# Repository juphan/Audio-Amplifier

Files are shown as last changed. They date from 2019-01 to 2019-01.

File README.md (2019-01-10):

# Audio-Amplifier
This audio amplifier circuit was designed to allow the user to physically change the volume of a plugged-in phone (or music player) by turning the dial of a connected dual gauge potentiometer. A phone needs to be connected in series with the potentiometer and the circuit. 

Phone -> Potentiometer -> Circuit (X7)

The circuit will also be connected to a wall outlet and be powered by dampening the incoming AC voltage into DC voltage. A pair of headphones can be connected to the board to project the amplified audio. 

The circuit design was taken from a schematic. This schematic was re-created on Eagle and board layout was performed on a 3x3 inch board. This project mainly involved setting up a circuit, basic board layout, ordering components, and soldering through hole components.

*Note - There is a small design issue. A female pin connector was not included on the circuit for the ground pin of the potentiometer. However, this issue can be solved by manually connecting the ground pin of the potentiometer with another ground in the circuit.

This repository contains the schematic that I re-created in Eagle, the board layout, the generated Gerber files from board layout, and the components list. There is also a picture of the final product.

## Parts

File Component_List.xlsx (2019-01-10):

*Note - Quantity of parts are meant for 3 sets of the Audio Amplifier circuit
Index | Piece | Quantity | Description | Part Number | Description | Unit Price ($) | Extended Price ($)
1 | Capacitors | 30 | 10uF | 445-8290-ND | CAP CER 10UF 16V X5R RADIAL | 0.319 | 9.57
2 |  | 6 | 1000uF | 1189-1583-1-ND | CAP ALUM 1000UF 20% 25V RADIAL | 0.67 | 4.02
3 |  | 12 | 0.1uF | 505-MKS2.1/63/5 (https://www.mouser.com/ProductDetail/WIMA/MKS2-1-63-5/?qs=sGAEpiMZZMv1cc3ydrPrFwgzP98AO9idLqHoQndgxWA%3d) | Film Capacitors 63V .1uF 5% | 0.289 | 3.47
4 |  | 6 | 680pF | 505-FKP2680/100/5, wima (https://www.mouser.com/ProductDetail/WIMA/FKP2D006801D00JSSD/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) | Film Capacitors 100V 680pF 5% TOL PCM 5 | 0.76 | 4.56
5 | Resistors | 10 | 100 ohm | S100QCT-ND | RES 100 OHM 1/4W 5% CF MINI | 0.041 | 0.41
6 |  | 10 | 1.1 kohm | S1.1KQCT-ND | RES 1.1K OHM 1/4W 5% CF MINI | 0.041 | 0.41
7 |  | 25 | 1 kohm | S1KQCT-ND | RES 1K OHM 1/4W 5% CF MINI | 0.03 | 0.75
8 |  | 10 | 3.3 kohm | S3.3KQCT-ND | RES 3.3K OHM 1/4W 5% CF MINI | 0.041 | 0.41
9 |  | 12 | 56 ohm | BC3946CT-ND | RES 56 OHM 0.4W 5% AXIAL | 0.197 | 2.36
10 |  | 6 | 56 ohm/ 1W | P56W-1BK-ND | RES 56 OHM 1W 5% AXIAL | 0.24 | 1.44
11 |  | 12 | 10 ohm | BC3924CT-ND | RES 10 OHM 0.4W 1% AXIAL | 0.197 | 2.36
12 | Diodes | 100 | 1N4148 DIODE | 1N4148FS-ND | DIODE GEN PURP 100V 200MA DO35 | 0.0345 | 3.45
13 |  | 12 | 1N4004 DIODE | 1N4004-TPMSCT-ND | DIODE GEN PURP 400V 1A DO41 | 0.104 | 1.25
14 | Voltage Regs | 3 | V_REG POS | LM338T/NOPB-ND | IC REG LINEAR POS ADJ 5A TO220-3 | 2.1 | 6.3
15 |  | 3 | V_REG NEG | LM337TFS-ND | IC REG LIN NEG ADJ 1.5A TO220-3 | 0.73 | 2.19
16 | LED | 3 | BLUE LED | 1125-1190-ND | LED BLUE DIFF 5MM OVAL T/H | 0.51 | 1.53
17 | Connectors | 6 | 2 PORT CONNECTOR | S7000-ND | CONN HEADER FEMALE 2POS .1" TIN | 0.32 | 1.92
18 |  | 1 | 3 PORT CONNECTOR | S7036-ND | CONN HEADER FEMALE 3POS .1" GOLD | 0.37 | 0.37
19 | OP Amp | 3 | OP AMP | OP275GPZ-ND | IC OPAMP AUDIO 9MHZ 8DIP | 3.43 | 10.29
20 | Transistors | 6 | NPN TRANSISTOR | MJE15032GOS-ND | TRANS NPN 250V 8A TO220AB | 1.58 | 9.48
21 |  | 6 | PNP TRANSISTOR | MJE15033GOS-ND | TRANS PNP 250V 8A TO220AB | 1.58 | 9.48
22 |  | 6 | NPN TRANSISTOR | 2N5551TAFSCT-ND | TRANS NPN 160V 0.6A TO-92 | 0.24 | 1.44
23 |  | 6 | PNP TRANSISTOR | 2N5401CS-ND | TRANS PNP 150V 0.6A TO-92 | 0.49 | 2.94
24 | Audio Jack | 3 | 3.5mm stereo jack | SJ1-3533NG | CONN JACK STEREO 3.5MM R/A | 1.17 | 3.51
 |  |  |  |  |  | Subtotal | 83.91

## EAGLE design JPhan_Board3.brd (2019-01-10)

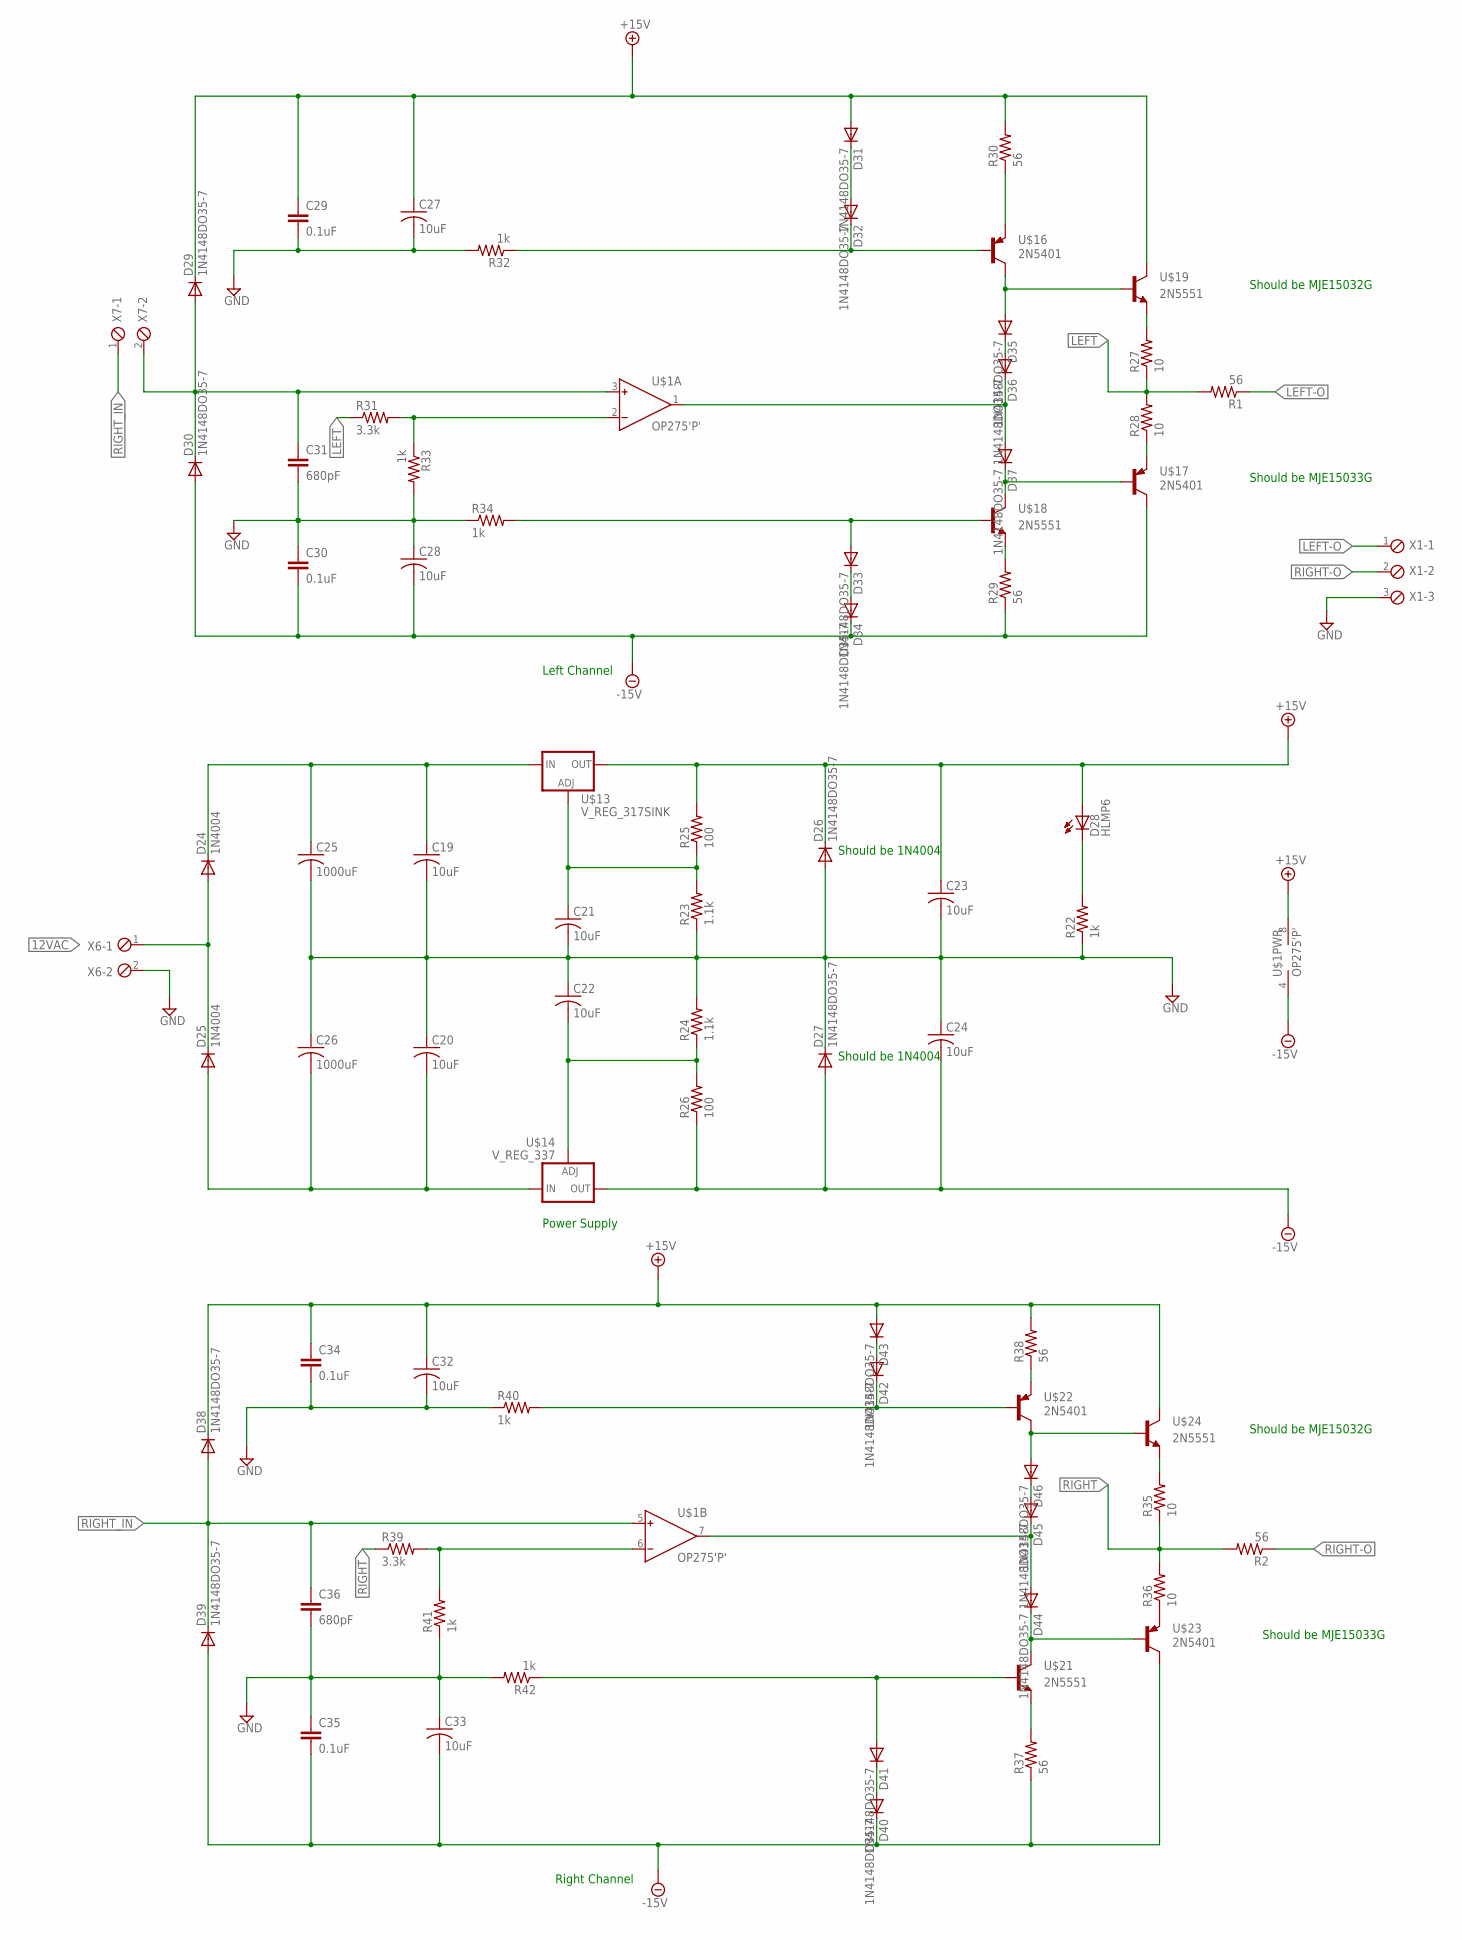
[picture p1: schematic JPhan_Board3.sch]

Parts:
C19, C20, C21, C22, C23, C24, C27, C28, C32, C33: 10uF; C025-030X050
C25, C26: 1000uF; C050-045X075
C29, C30, C34, C35: 0.1uF; C025-024X044
C31, C36: 680pF; C025-024X044
D24, D25: 1N4004; DO41-10
D26, D27, D29, D30, D31, D32, D33, D34, D35, D36, D37, D38, D39, D40, D41, D42, D43, D44, D45, D46: 1N4148DO35-7; DO35-7
D28: HLMP6
R1, R2, R29, R30, R37, R38: 56; 0204/7
R22, R32, R33, R34, R40, R41, R42: 1k; 0204/7
R23, R24: 1.1k; 0204/7
R25, R26: 100; 0204/7
R27, R28, R35, R36: 10; 0204/7
R31, R39: 3.3k; 0204/7
U$1: OP275'P'; DIL08
U$13: V_REG_317SINK; TO220-ADJ
U$14: V_REG_337; TO220-ADJ-NEG
U$16, U$17, U$22, U$23: 2N5401
U$18, U$19, U$21, U$24: 2N5551
X1: MPT3; 3POL254
X6, X7: MPT2; 2POL254

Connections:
12VAC: D24.A, D25.C, X6.1
+15V: C23.1, C27.1, C29.1, C32.1, C34.1, D26.C, D28.A, D29.C, D31.A, D38.C, D43.A, R25.2, R30.2, R38.2, U$1.8 (V+), U$13.OUT, U$19.C, U$24.C
-15V: C24.2, C28.2, C30.2, C33.2, C35.2, D27.A, D30.A, D34.C, D39.A, D40.C, R26.1, R29.1, R37.1, U$1.4 (V-), U$14.OUT, U$17.C, U$23.C
GND: C19.2, C20.1, C21.2, C22.1, C23.2, C24.1, C25.2, C26.1, C27.2, C28.1, C29.2, C30.1, C31.2, C32.2, C33.1, C34.2, C35.1, C36.2, D26.A, D27.C, R22.1, R23.1, R24.2, R32.2, R33.2, R34.1, R40.1, R41.1, R42.2, X1.3, X6.2
LEFT: R1.2, R27.1, R28.2, R31.1
LEFT-O: R1.1, X1.1
unnamed: C31.1, D29.A, D30.C, U$1.3 (IN+), X7.2
unnamed: R31.2, R33.1, U$1.2 (IN-)
unnamed: C19.1, C25.1, D24.C, U$13.IN
unnamed: C20.2, C26.2, D25.A, U$14.IN
unnamed: C21.1, R23.2, R25.1, U$13.ADJ
unnamed: C22.2, R24.1, R26.2, U$14.ADJ
unnamed: D28.K, R22.2
unnamed: D35.A, U$16.C, U$19.B
unnamed: D32.C, R32.1, U$16.B
unnamed: D31.C, D32.A
unnamed: R30.1, U$16.E
unnamed: D35.C, D36.A
unnamed: D36.C, D37.A, U$1.1 (OUT)
unnamed: D37.C, U$17.B, U$18.C
unnamed: R29.2, U$18.E
unnamed: D33.C, D34.A
unnamed: R27.2, U$19.E
unnamed: R28.1, U$17.E
unnamed: D33.A, R34.2, U$18.B
unnamed: R39.2, R41.2, U$1.6 (IN-)
unnamed: D40.A, D41.C
unnamed: R37.2, U$21.E
unnamed: D44.C, U$21.C, U$23.B
unnamed: D44.A, D45.C, U$1.7 (OUT)
unnamed: D45.A, D46.C
unnamed: D46.A, U$22.C, U$24.B
unnamed: D42.A, D43.C
unnamed: D42.C, R40.2, U$22.B
unnamed: D41.A, R42.1, U$21.B
unnamed: R35.2, U$24.E
unnamed: R36.1, U$23.E
unnamed: R38.1, U$22.E
RIGHT: R2.2, R35.1, R36.2, R39.1
RIGHT-O: R2.1, X1.2
RIGHT_IN: C36.1, D38.A, D39.C, U$1.5 (IN+), X7.1

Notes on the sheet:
Power Supply
Left Channel
Right Channel
Should be MJE15032G
Should be MJE15033G
Should be 1N4004

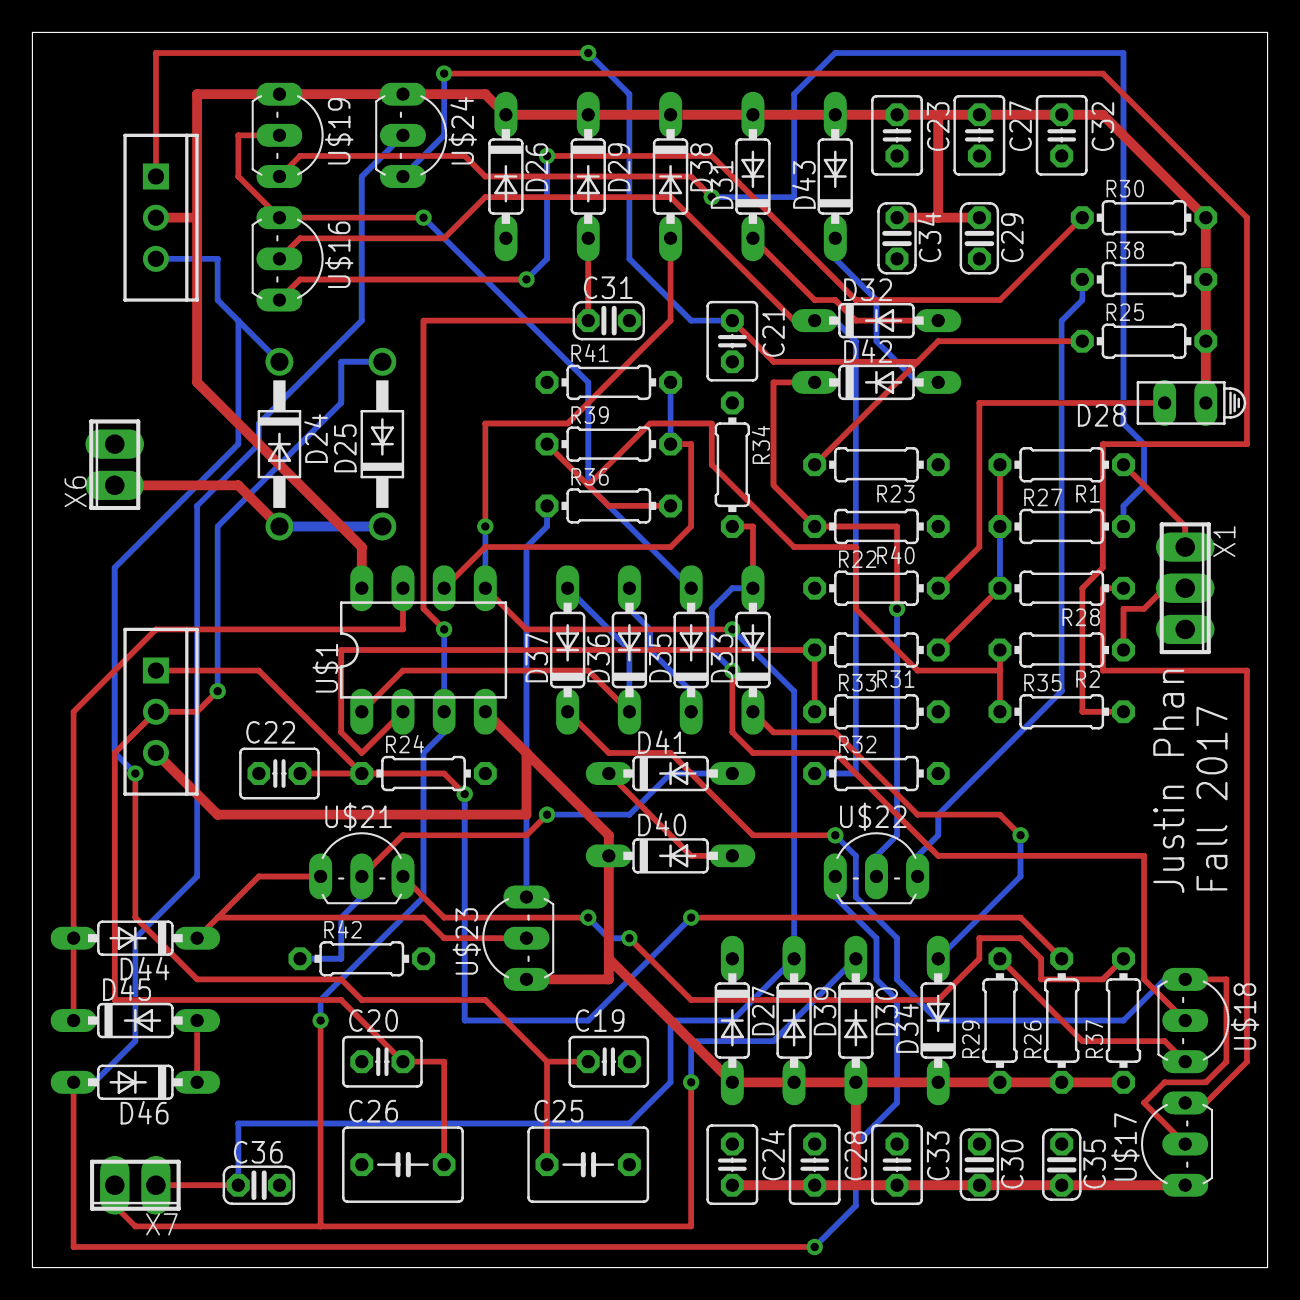
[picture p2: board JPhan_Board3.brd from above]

Board: 2 copper layers, 76.2 x 76.2 mm, 78 parts (0 on the bottom side), 41 nets.
